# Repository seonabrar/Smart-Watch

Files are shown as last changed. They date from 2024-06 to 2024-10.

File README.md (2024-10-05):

# SMART WATCH – HEALTH AND FITNESS MONITORING SYSTEM

## ABSTRACT
This project presents the design and implementation of a multi-functional embedded system integrating various sensors and modules for environmental monitoring, user interaction, and health metrics. The core of the system is the Seeed Studio Xiao NRF52840 microcontroller, which orchestrates the operation of several connected components. 

## INTRODUCTION
The purpose of this document is to specify the requirements, implementation, and testing plan for Health and Fitness Monitoring System, also referred to as the "Smart Watch." This system is designed to cater to outdoor enthusiasts by providing real-time tracking and monitoring of vital health metrics and activity levels. The document aims to outline what the device is intended to achieve, how it has implemented, and the testing procedures to ensure that it meets the specified requirements. The ultimate goal is to enhance performance, safety, and overall well-being during outdoor activities such as hiking, trail running, and mountain biking.

## Block Diagram

This block diagram illustrates the connections between the Seeed Xiao Nrf52840 microcontroller and various sensors used in the Health and Fitness Monitoring System. The sensors connected via I2C are shown in blue arrows (input sensors), while the display connected via SPI is shown with a red arrow (output sensor).

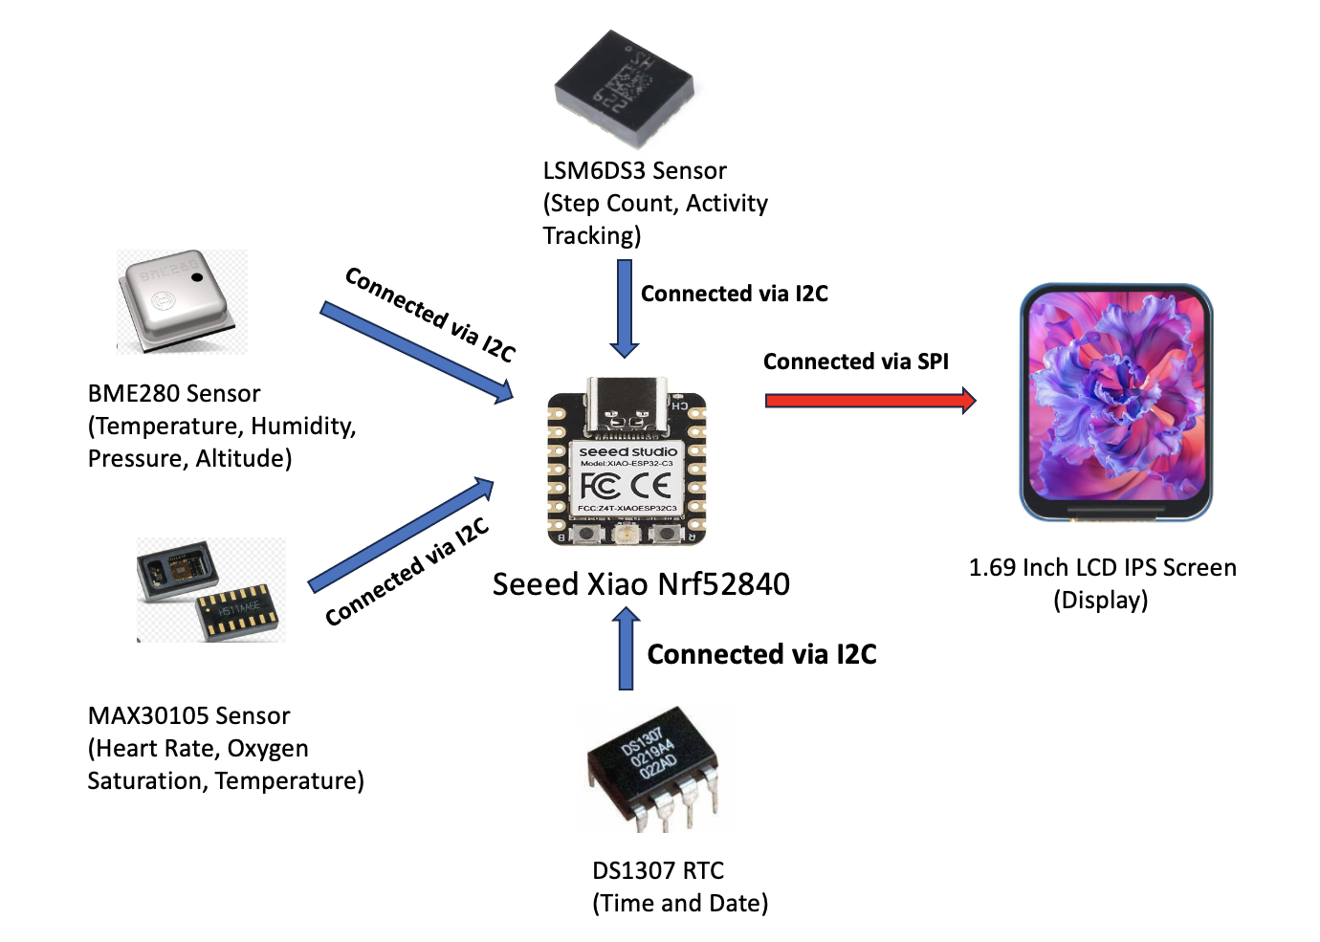
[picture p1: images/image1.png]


## Schematic

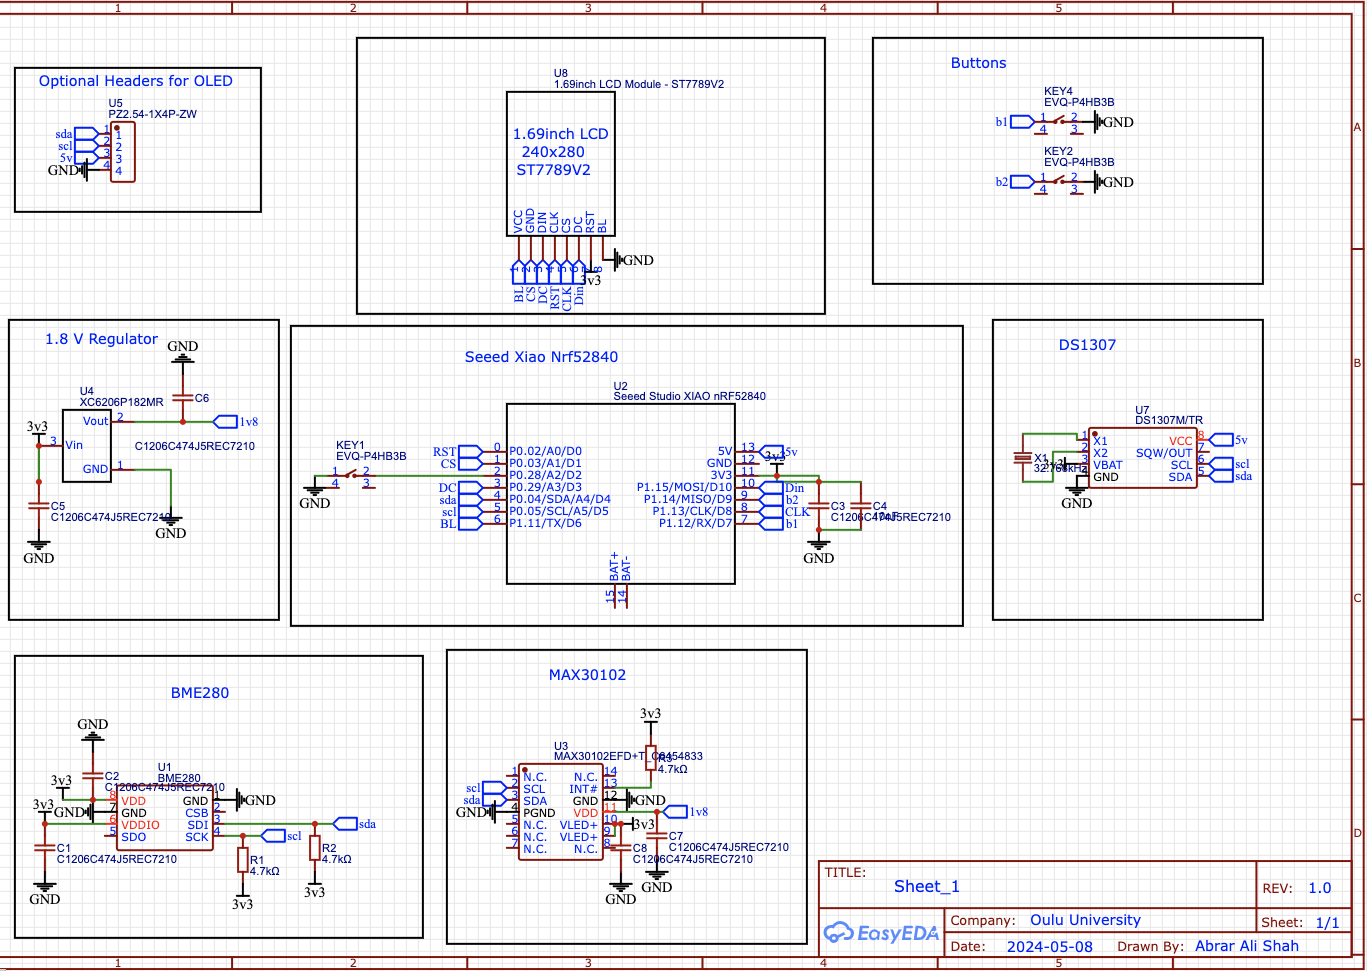
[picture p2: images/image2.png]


## PCB

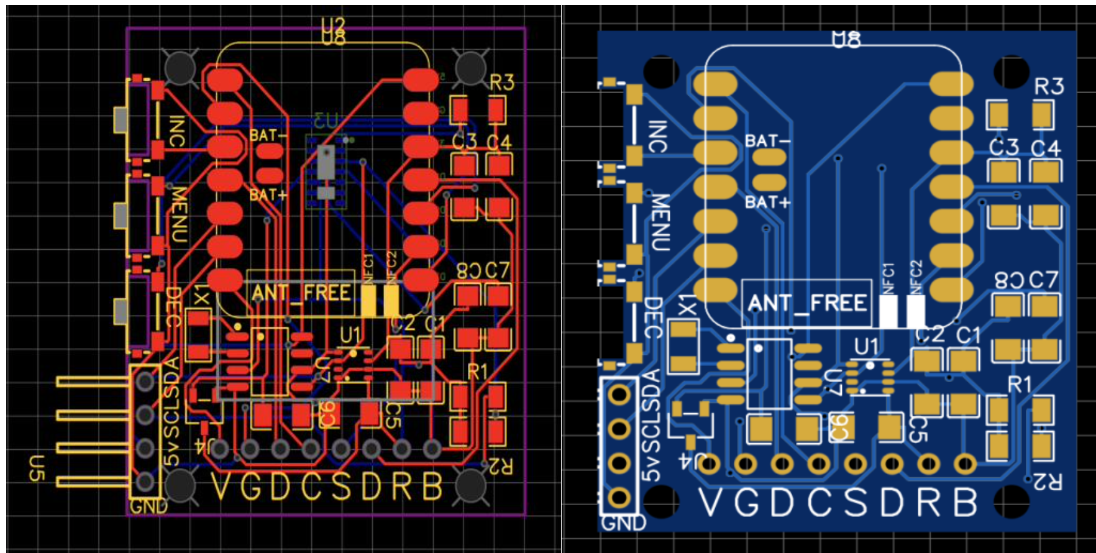
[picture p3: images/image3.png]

            Figure:  2D - PCB Layout for the Device.

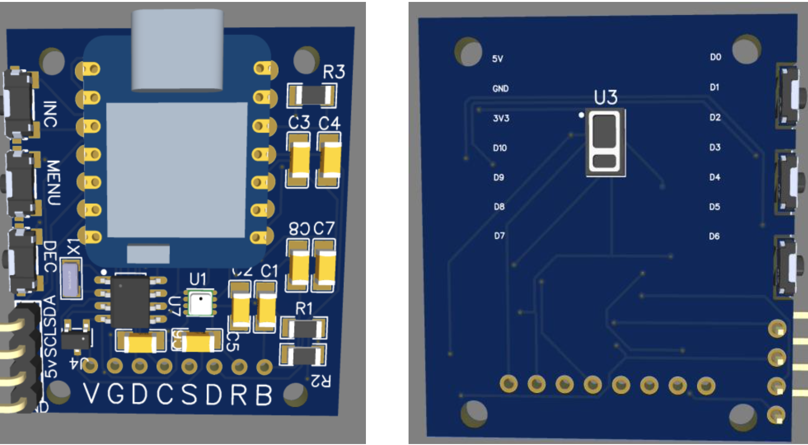
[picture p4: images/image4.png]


             Figure: 3D - PCB Layout for the Device.

## Software 
The software for the Seeed Xiao Based Health and Fitness Monitoring System was designed to manage sensor data acquisition, processing and display management. The software architecture was modular to facilitate ease of development, testing, and future enhancements.

## Software Architecture
The software is divided into several modules, each responsible for specific functionalities:
• Sensor Data Acquisition: Manages communication with sensors (MAX30105, BME280, LSM6DS3, DS1307) using I2C and SPI protocols to collect raw data.
• Data Processing and Analysis: Processes raw sensor data to derive meaningful health metrics and activity data.
• Display Management: Updates the 1.69 Inch LCD IPS screen with the latest health metrics and activity data.
• Power Management: Implements various power-saving strategies to extend battery life, including using deep sleep mode during periods of inactivity.

## Power Consumption and Battery Life Calculation

### Step 1: Current Consumption of Each Component

The current consumption of each component is as follows:

- **Seeed Xiao NRF52840**:
  - Active Mode (without BLE): ~6 mA
  - Idle Mode: ~1.5 mA
  - Deep Sleep: ~0.1 mA

- **LSM6DS3 (Accelerometer + Gyroscope)**:
  - Active Mode: ~0.67 mA
  - Power Down Mode: ~1 µA

- **MAX30105 (Heart Rate Monitor)**:
  - Typical: ~1.6 mA (continuous monitoring)
  - Standby: ~0.7 µA

- **DS1307 (RTC)**:
  - Typical: ~1.5 mA (when accessing data)
  - Standby: ~1.1 µA (when only keeping time)

- **BME280 (Temperature, Humidity, Pressure Sensor)**:
  - Active Mode: ~0.68 mA
  - Sleep Mode: ~0.1 µA

- **ST7789 Display**:
  - Active (with backlight on): ~7 mA
  - Standby: ~0.2 mA

### Step 2: Total Current Consumption

Assuming all components are active (no sleep mode), the total current consumption is calculated as:

- **Seeed Xiao NRF52840** (Active Mode): 6 mA
- **LSM6DS3** (Active Mode): 0.67 mA
- **MAX30105** (Typical): 1.6 mA
- **DS1307** (Typical): 1.5 mA
- **BME280** (Active Mode): 0.68 mA
- **ST7789 Display** (with backlight): 7 mA

**Total Current Consumption**:  
`6 mA + 0.67 mA + 1.6 mA + 1.5 mA + 0.68 mA + 7 mA = 17.45 mA`

### Step 3: Battery Life Calculation

Using a **3.7V 300mAh LiPo battery**:

- **Battery Capacity**: 300 mAh = 0.3 Ah
- **Battery Life** (in hours):  
  `Battery Life = Battery Capacity (Ah) / Total Current Consumption (A)`  
  `Battery Life = 0.3 Ah / 0.01745 A ≈ 17.2 hours`

## Procedure

- When Smart watch is Powered it shows Date and Time as below on Display.
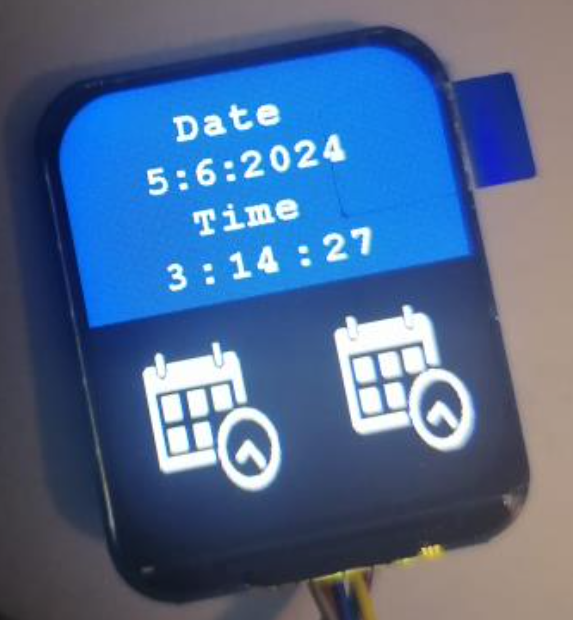
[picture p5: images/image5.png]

- When Button is pressed, screen changes and shows Heart Rate as below on Display.
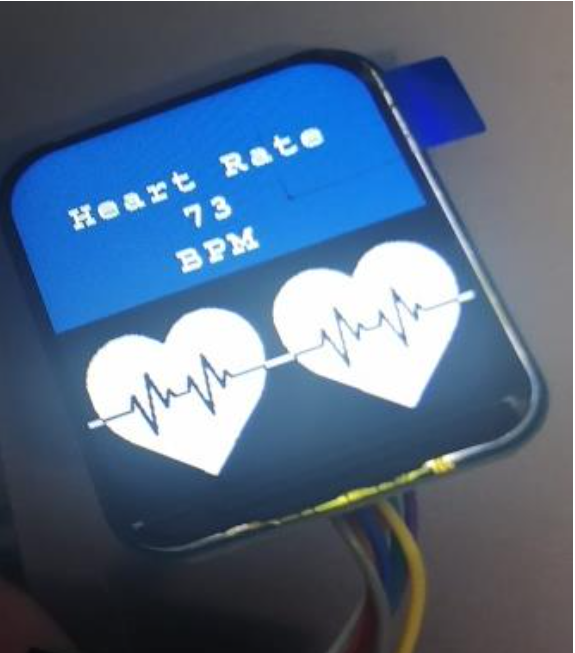
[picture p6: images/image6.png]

- When Button is pressed, screen changes and shows Tempertature and Humidity as below on Display.
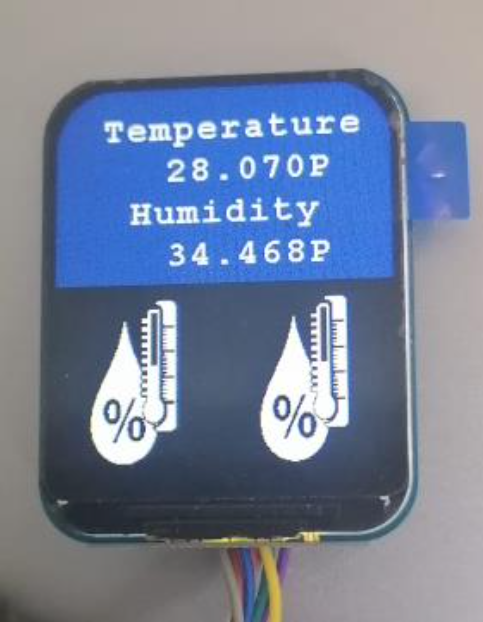
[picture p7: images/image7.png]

- When Button is pressed, screen changes and shows Altitude and Pressure as below on Display.
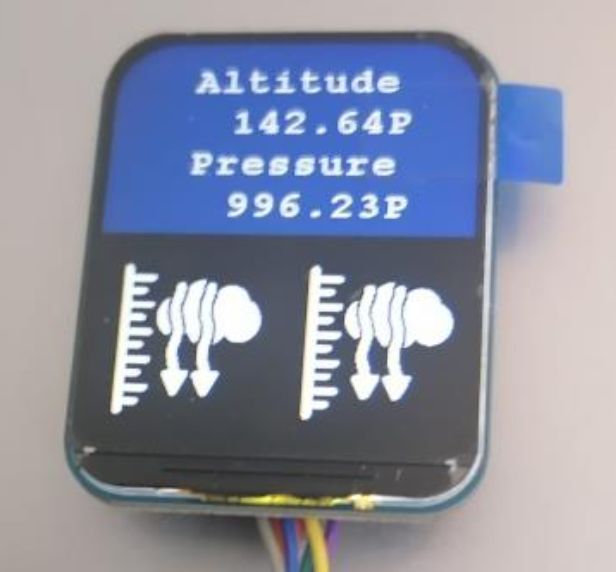
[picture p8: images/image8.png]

- When Button is pressed, screen changes and shows Steps Count as below on Display and so on.
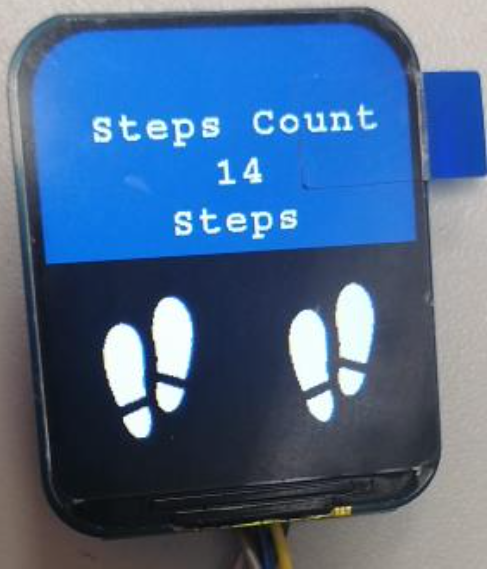
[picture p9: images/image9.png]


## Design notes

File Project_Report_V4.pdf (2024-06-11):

# SMART WATCH – HEALTH AND FITNESS MONITORING SYSTEM

Embedded System Project

ABSTRACT
This project presents the design and implementation of

a multi-functional embedded system integrating various

sensors and modules for environmental monitoring,

user interaction, and health metrics. The core of the

system is the Seeed Studio Xiao NRF52840

microcontroller, which orchestrates the operation of

several connected components.

GROUP 4

Abrar Ali Shah
Sabbir Hossain

Project Repository
https://github.com/seonabrar/Smart-Watch

Table of Contents

### 1 INTRODUCTION

1.1 Purpose

The purpose of this document is to specify the requirements, implementation, and testing

plan for Health and Fitness Monitoring System, also referred to as the "Smart Watch." This

system is designed to cater to outdoor enthusiasts by providing real-time tracking and

monitoring of vital health metrics and activity levels. The document aims to outline what

the device is intended to achieve, how it has implemented, and the testing procedures to

ensure that it meets the specified requirements. The ultimate goal is to enhance

performance, safety, and overall well-being during outdoor activities such as hiking, trail

running, and mountain biking.

1.2 Scope

The scope of this document includes three main sections: requirement specification,

implementation specification, and testing plan.

Requirement Specification: This section defines the functional, physical, and electrical

requirements of the smart watch. It includes detailed descriptions of what the device must

do, how it should operate, and any constraints or limitations that must be considered.

Implementation Specification: This section provides a detailed description of the

implementation techniques, hardware components, software architecture, and protocols

used in the development of the smart watch. It covers the design of the printed circuit board

(PCB), the selection of sensors and other components, and the software that will drive the

device.

Test Plan: This section outlines the tests that has been conducted during and after the

development process to ensure the device meets the specified requirements. The test plan

includes basic hardware tests, unit tests, integration tests, system tests, and regression tests.

1.3 Human Resources

The project team for Health and Fitness Monitoring System consists of Abrar Shah and

Sabbir Hossain from group 4. Both team members worked in all project phases. The

responsibilities are divided as follows:

Areas | Remarks | Group Member
Planning & Research | Initial Project Planning and Research | Abrar Shah, Sabbir Hossain
| Component Selection and Procurement | Abrar Shah, Sabbir Hossain
Electronics | Design and development of the electronic circuits and PCB layout by. | Abrar Shah, Sabbir Hossain
Software | Development of the firmware and software to operate the device. | Abrar Shah

Integration | Integration of hardware and software components to create a functional prototype. | Abrar Shah, Sabbir Hossain
Documentation | Creation and maintenance of project documentation, including this specification document. | Sabbir Hossain
Testing | Conducting tests to ensure the device meets all specified requirements. | Abrar Shah, Sabbir Hossain
Final Documentation | Creation and maintenance of project documentation, including this specification document. | Abrar Shah, Sabbir Hossain

1.4 Acronyms and Abbreviations

MCU: Microcontroller Unit

PCB: Printed Circuit Board

TFT: Thin Film Transistor

I2C: Two-wire serial communication protocol

ADC: Analog to Digital Converter

1.5 Overview

Health and Fitness Monitoring System is a smart watch designed for outdoor enthusiasts.

The primary objective of this device is to monitor and track vital health metrics and physical activity levels during outdoor pursuits. The device includes functionalities such

as heart rate monitoring, oxygen saturation measurement, step count tracking, altitude and

pressure, temperature, humidity and time keeping.

The smart watch is built around the Seeed Xiao Nrf52840 microcontroller, which provides

the necessary computational power. The device uses a variety of sensors to collect data,

which is then processed and displayed on a high-resolution graphical interface. The smart

watch is designed to be compact, lightweight, and durable, making it suitable for use in a

variety of outdoor environments.

### 2 Requirement Specification

2.1 Functional Requirements

Real-Time Health Monitoring:

The device provided accurate and real-time monitoring of vital health metrics, including

heart rate, oxygen saturation, and temperature. The MAX30105 sensor was used for this

purpose, leveraging its photoplethysmography (PPG) technology to measure changes in

blood volume. This enabled reliable heart rate tracking with an accuracy of ±1 bpm.

Activity Tracking and Analysis:

The device was capable of tracking and analyzing user activity levels, including step count

and calorie expenditure. The LSM6DS3 sensor, an accelerometer and gyroscope, was

utilized to detect motion and orientation changes with high precision. This allowed for

accurate step count tracking and detailed analysis of physical activity, enabling users to

monitor their fitness levels and performance during outdoor activities.

Environmental Awareness:

The device incorporated environmental sensors to provide real-time information about

ambient conditions such as temperature, humidity, pressure and altitude. The BME280

sensor was used, offering a wide measurement range and high accuracy (±1°C for

temperature, ±3% for humidity, and ±1 hPa for pressure). This allowed users to stay

informed about changing weather conditions, optimizing their performance based on

temperature and humidity levels, and ensuring safety during various outdoor activities.

Time and Date Tracking:

The device includes a DS1307 real-time clock (RTC) for accurate time and date keeping.

This is essential for logging activity data and synchronizing with external devices. The

RTC module ensures that timekeeping remains accurate even when the device is powered

off.

User Interface and Display:

The device featured a user-friendly interface with a 1.69 Inch LCD IPS screen, which had

a resolution of 240x280 pixels. This high-resolution display ensured clear and intuitive

visualization of health and activity data. The IPS technology provided wide viewing angles

and vibrant colors, enhancing the user experience by making the display easily readable in

various lighting conditions. The graphical interface allowed users to navigate through

different features, customize data visualization, and stay informed about their health and

activity levels.

2.2 Electrical Requirements

- Operating Voltage: The device operated at a standard voltage of 3.3V, suitable for

all components, including the microcontroller, sensors, and display. This ensured

efficient power consumption and compatibility across all hardware elements.

- Power Source and Management: The device features a rechargeable 3.7V

300mAh lithium-polymer (Li-Po) battery, providing sufficient capacity for at least

one day of regular use. To maximize battery life, various power management

techniques, including low-power modes and efficient task scheduling, have been

implemented. The Seeed Xiao NRF52840 microcontroller's deep sleep mode, which

reduces power consumption to an ultra-low 5 μA, is used during periods of

inactivity.

The device includes a micro-USB port for convenient recharging of the Li-Po

battery, ensuring compatibility with commonly available chargers and cables. The

integrated charging circuit manages the recharging process safely and efficiently,

preventing overcharging and ensuring battery longevity.

Power Specifications:

Battery: 3.7V 300mAh Li-Po

Operating Voltage: 3.3V @ 200mA

Charging Current: 50mA/100mA

Input Voltage: 5V DC

Standby Power Consumption: <5 μA

Overall, the device offers efficient power management and ultra-low power

consumption, making it suitable for extended use with minimal recharging

requirements.

2.3 Mechanical Requirements

The enclosure for end node device and main controller is 3d printed in fab lab.

### 3 Implementation Specification

3.1 Hardware

3.1.1 Components

1. MAX30105 Sensor:

The MAX30105 is an integrated particle-sensing module. It includes internal LEDs,

photodetectors, optical elements, and low-noise electronics with ambient light

rejection. The MAX30105 provides a complete system solution to ease the design-

in process of smoke detection applications including fire alarms. Due to its

extremely small size, the MAX30105 can also be used as a smoke detection sensor

for mobile and wearable devices. The MAX30105 operates on a single 1.8V power

supply and a separate 5.0V power supply for the internal LEDs. It communicates

through a standard I2C-compatible interface. The module can be shut down through

software with zero standby current, allowing the power rails to remain powered at

all times.

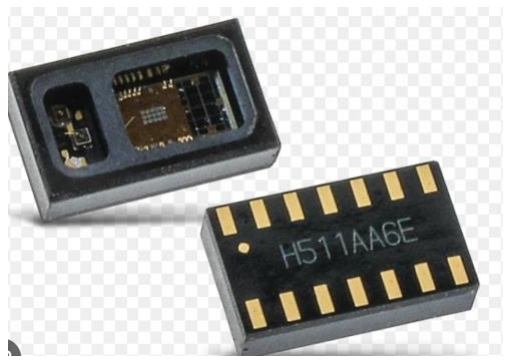
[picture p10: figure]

Figure: 3.1 MAX30105 sensing module.

2. BME280 Sensor:

The BME280 is as combined digital humidity, pressure and temperature sensor

based on proven sensing principles. The sensor module is housed in an extremely compact metal-lid LGA package with a footprint of only 2.5 × 2.5 mm² with a height

of 0.93 mm. Its small dimensions and its low power consumption allow the

implementation in battery driven devices such as handsets, GPS modules or

watches. The BME280 is register and performance compatible to the Bosch

Sensortec BMP280 digital pressure sensor. The BME280 achieves high

performance in all applications requiring humidity and pressure measurement.

These emerging applications of home automation control, in-door navigation,

fitness as well as GPS refinement require a high accuracy and a low TCO at the

same time. The humidity sensor provides an extremely fast response time for fast

context awareness applications and high overall accuracy over a wide temperature

range. The pressure sensor is an absolute barometric pressure sensor with extremely

high accuracy and resolution and drastically lower noise than the Bosch Sensortec

BMP180. The integrated temperature sensor has been optimized for lowest noise

and highest resolution. Its output is used for temperature compensation of the

pressure and humidity sensors and can also be used for estimation of the ambient

temperature. The sensor provides both SPI and I²C interfaces and can be supplied

using 1.71 to 3.6 V for the sensor supply VDD and 1.2 to 3.6 V for the interface

supply VDDIO. Measurements can be triggered by the host or performed in regular

intervals. When the sensor is disabled, current consumption drops to 0.1 µA.

BME280 can be operated in three power modes:

- Sleep mode
- Normal mode
- Forced mode

In order to tailor data rate, noise, response time and current consumption to the needs

of the user, a variety of oversampling modes, filter modes and data rates can be

selected.

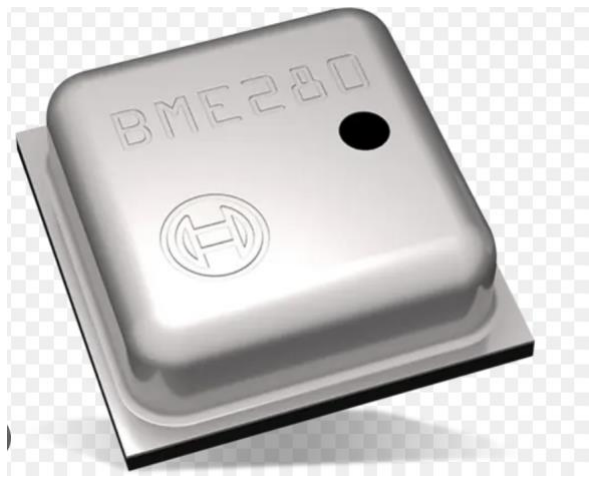
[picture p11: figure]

Figure: 3.2 BME280 Sensor

3. LSM6DS3 Sensor:

The LSM6DS3 is an advanced system-in-package that integrates a high-

performance 3-axis digital accelerometer and a 3-axis digital gyroscope. This sensor

module is designed to deliver exceptional motion sensing capabilities while

maintaining low power consumption, making it ideal for a variety of applications

including smartphones, tablets, and wearable devices.

The LSM6DS3 offers power-efficient modes, with consumption as low as 1.25 mA

in high-performance mode and even lower in power-down or low-power modes. It

supports an “always-on” experience with low power consumption for both the

accelerometer and gyroscope. This feature makes it suitable for applications

requiring continuous motion detection, such as pedometers, step counters, and tilt

functions.

In terms of sensing capabilities, the LSM6DS3 provides full-scale acceleration

ranges of ±2g, ±4g, ±8g, and ±16g, and angular rate ranges of ±125, ±250, ±500,

±1000, and ±2000 degrees per second (dps). The module also includes an integrated

temperature sensor, which enhances measurement accuracy by compensating for

temperature variations.

The LSM6DS3 is equipped with a smart FIFO buffer up to 8 kB, which can store

data for dynamic batching and supports advanced features such as pedometer, significant motion detection, and tilt functions. The sensor module’s high robustness

to mechanical shock and its compact footprint (2.5 mm x 3 mm x 0.83 mm) make it

a preferred choice for reliable product design.

Additionally, the LSM6DS3 offers configurable event detection and interrupt

generation, enabling applications such as tap and double-tap detection, free-fall

detection, and 6D orientation detection. Communication with the host processor is

facilitated through SPI or I2C serial interfaces, ensuring easy integration into a

variety of systems.

Overall, the LSM6DS3 is a versatile and efficient sensor module that provides

precise motion detection and measurement capabilities, making it suitable for a wide

range of consumer and industrial applications.

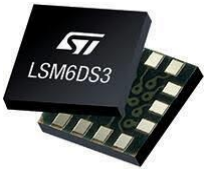
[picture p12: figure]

Figure: 3.3 LSM6DS3 Sensor

4. DS1307 RTC:

The DS1307 real-time clock was used to keep accurate time and date, which was

essential for logging activity data and synchronizing with external devices. The RTC

module ensured that timekeeping remained accurate even when the device was

powered off.

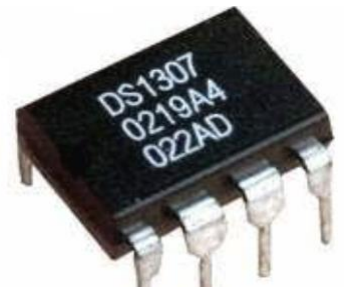
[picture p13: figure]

Figure 3.4 DS1307 RTC

5. 1.69 Inch LCD IPS Screen:

For the display we have used the 1.69” display with rounded corners. These IPS

display gives a very nice display contrast and colour saturation. This display uses

the ST7789 display driver. The ST7789 can support SPI bus frequency up to

100MHz. This will enable us to driver the display much faster providing better FPS.

The backlight is controlled using a N-Channel MOSFET. PWM is used to

control the brightness.

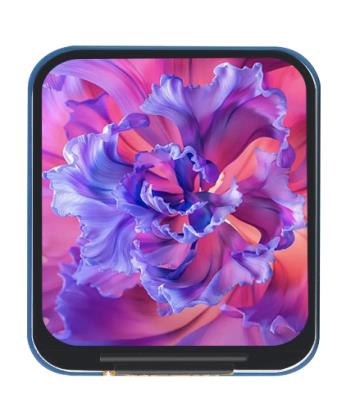
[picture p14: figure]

Figure: LCD display

### 3.1.2 Block Diagram

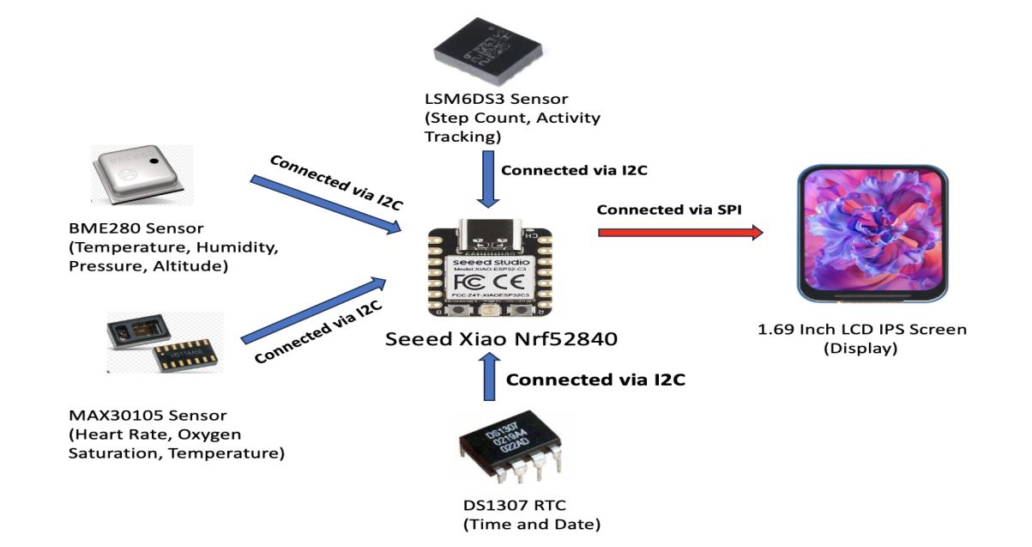
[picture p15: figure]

Figure: 3.5 Block Diagram of the overall device.

Table 3.1: Component Connections and Descriptions for the Device

Component | Description | Connection Type
Seeed Xiao Nrf52840 | Microcontroller | -
BME280 Sensor | Temperature, Humidity, Pressure, Altitude | I2C
MAX30105 Sensor | Heart Rate, Oxygen Saturation, Temperature | I2C
LSM6DS3 Sensor | Step Count, Activity Tracking | I2C
DS1307 RTC | Time and Date | I2C
1.69 Inch LCD IPS Screen | Display | SPI

This block diagram illustrates the connections between the Seeed Xiao Nrf52840

microcontroller and various sensors used in the Health and Fitness Monitoring System. The sensors connected via I2C are shown in blue arrows (input sensors), while the display

connected via SPI is shown with a red arrow (output sensor).

### 3.1.3 Microcontroller

Seeed Studio XIAO nRF52840 Sense is carrying Bluetooth 5.0 wireless capability and is

able to operate with low power consumption. Featuring onboard IMU and PDM, it can be

your best tool for embedded Machine Learning projects.

Features

- Versatile Microcontroller: Incorporate the Nordic nRF52840 chip with FPU,

operating up to 64 MHz, mounted multiple development ports, supported by

Arduino / CircuitPython

- Wireless Capabilities: Implement Bluetooth 5.0, BLE functions with onboard

antenna, also provide NFC connectivity

- Elaborate Power Design: Provide ultra-low power consumption as 5 μA in deep

sleep mode while supporting lithium battery charge management

- Advanced onboard Functionality: Assemble additional digital microphone and 6-

axis IMU in the tiny board for embedded Machine Learning applications

- Thumb-sized Design: 21 x 17.5mm, Seeed Studio XIAO series classic form-factor,

suitable for wearable devices

Seeed Studio XIAO nRF52840 Sense has an ultra-low power consumption of only 5 μA in

the deep sleep mode, the embedded BQ25101 chip supports battery charge management

which prolongs its use time. Moreover, Seeed Studio XIAO nRF52840 Sense supports the

USB Type-C interface which can supply power and download code. It also has rich On-

chip Memory of 1 MB flash and 256 kB RAM, and an Onboard Memory of 2 MB QSPI

flash. There are 11 digital i/o that can be used as PWM pins and 6 analog i/o that can be

used as ADC pins. It supports UART, IIC, and SPI all three common serial ports. 1 Reset

button, 1 3in-one LED, 1 Charge LED, and 1 Bluetooth antenna are on board, allowing

developers to debug their code very easily.

As the advanced yet smaller version of the Seeed Studio XIAO nRF52840, it carries two

extra onboard sensors. One of them is a digital microphone created through Pulse Density

Modulation(PDM) module on the nRF52840 chip. It can receive audio data in real-time

which allows it can be used for audio recognition. The board can receive audio data through

the MSM261D3526H1CPM microphone. The other one is 6-axis Inertial Measurement

Unit(IMU) which can be applied in TinyML projects like gesture recognition.

The powerful performance makes it perfect for TinyML AIoT projects requiring

gesture/voice recognition, and the tiny size allows it to be used in wearable devices and

Internet of Things projects, not just for prototypes but the mass production. Furthermore,

Seeed Studio XIAO nRF52840 Sense is friendly to the communities for its strong software

compatibilities, which supports Arduino, Micropython, and CircuitPython. Except for the

software, flexible I/O allows it to speak to almost any external device.

### 3.1.4 Schematic

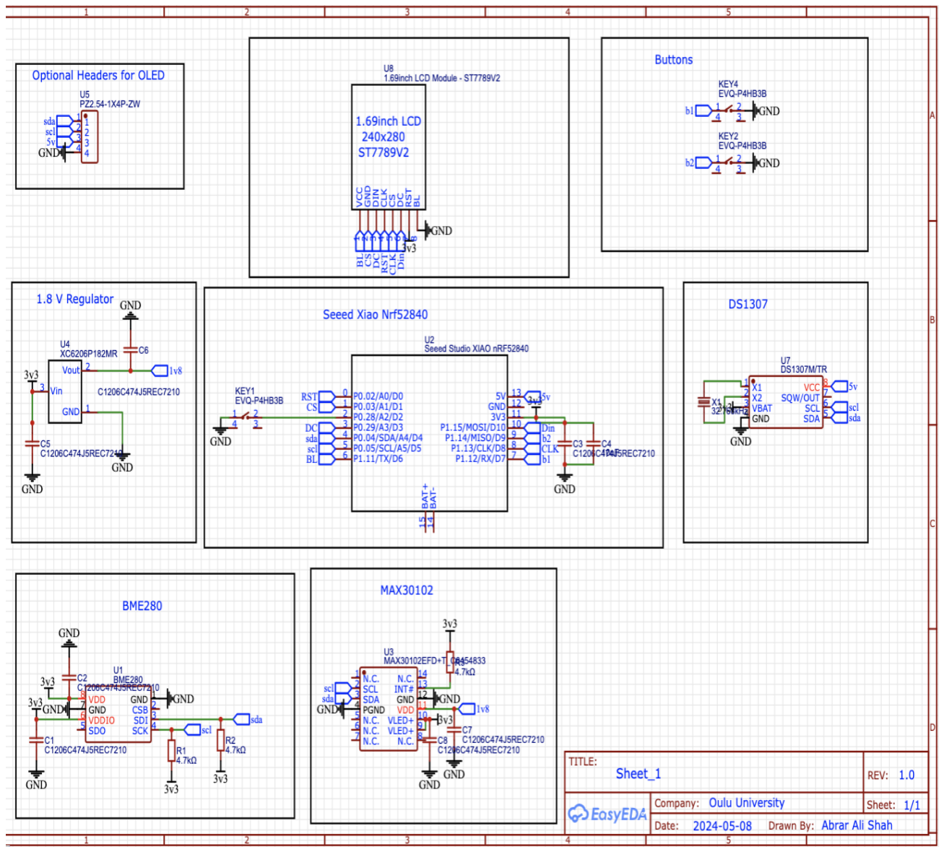
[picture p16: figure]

Figure 3.6: Schematic Diagram of the device

### 3.1.5 PCB

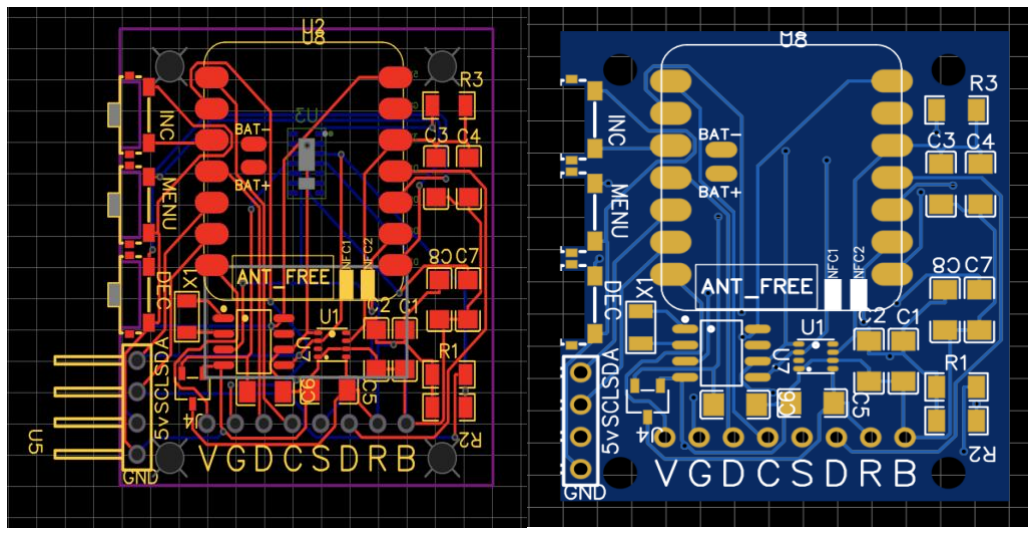
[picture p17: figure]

Figure: 3.7 2D - PCB Layout for the Device.

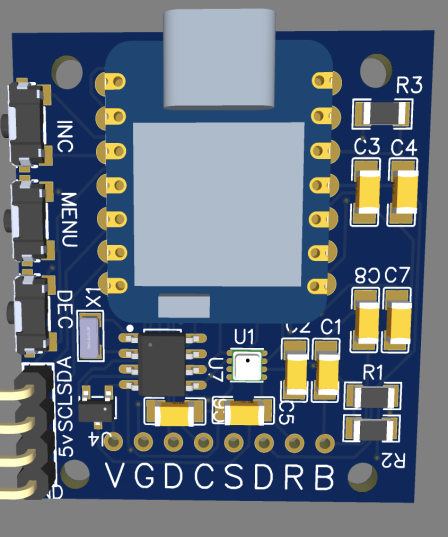
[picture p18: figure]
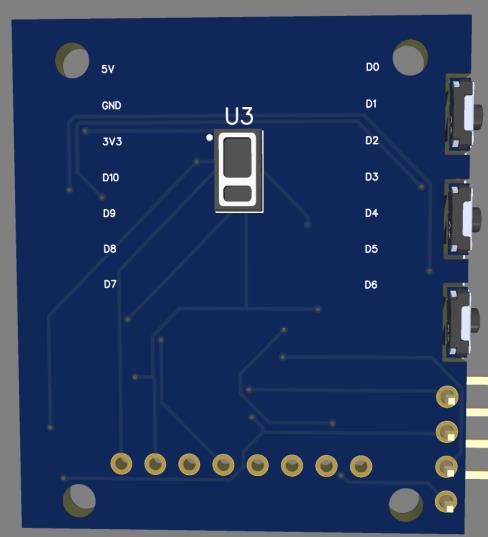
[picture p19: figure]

Figure: 3.8 3D - PCB Layout for the Device.

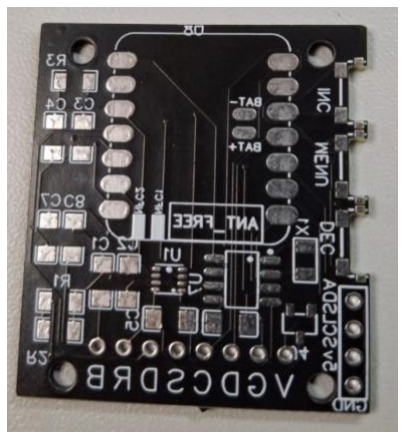
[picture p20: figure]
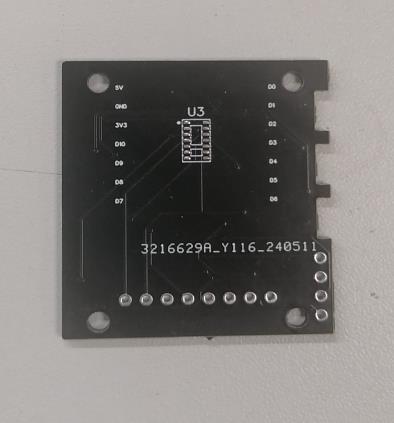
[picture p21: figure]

Figure: 3.9 Before assembly of components on the device.

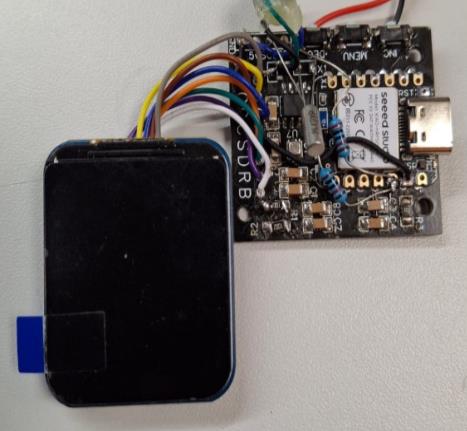
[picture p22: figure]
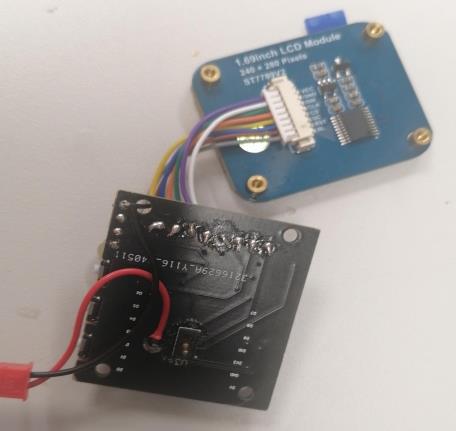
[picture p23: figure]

Figure: 3.10 After assembly of components on the device.

### 3.2 Software

The software for the Seeed Xiao Based Health and Fitness Monitoring System was

designed to manage sensor data acquisition, processing and display management. The

software architecture was modular to facilitate ease of development, testing, and future

enhancements.

### 3.2.1 Software Architecture

The software is divided into several modules, each responsible for specific functionalities:

- Sensor Data Acquisition: Manages communication with sensors (MAX30105,

BME280, LSM6DS3, DS1307) using I2C and SPI protocols to collect raw data.

- Data Processing and Analysis: Processes raw sensor data to derive meaningful

health metrics and activity data.

- Display Management: Updates the 1.69 Inch LCD IPS screen with the latest health

metrics and activity data.

- Power Management: Implements various power-saving strategies to extend battery

life, including using deep sleep mode during periods of inactivity.

- #include <st7789v2.h>
- #include "SPI.h"
- #include "Logo.h"

•
- #include "Wire.h"

•
- #include "MAX30105.h"
- #include "heartRate.h"

•
- #include <DS1307.h>

•
- #include <Adafruit_Sensor.h>
- #include <Adafruit_BME280.h>

•
- #include "LSM6DS3.h"

•
- DS1307 rtc;

•
- MAX30105 particleSensor;

•
- | #define CLEAR_STEP | true
- #define NOT_CLEAR_STEP false

•
- //Create a instance of class LSM6DS3
- LSM6DS3 pedometer(I2C_MODE, 0x6A); //I2C device address 0x6A

•
- const byte RATE_SIZE = 5; // Increase this for more averaging. 4 is good.
- byte rates[RATE_SIZE]; // Array of heart rates
- byte rateSpot = 0;
- long lastBeat = 0; // Time at which the last beat occurred

•
- float beatsPerMinute;
- int beatAvg;

•
- st7789v2 Display;

•
- #define BUTTON_PIN D7

•
- unsigned long lastDisplayUpdate = 0;

•
- // Variable to track the button press count
- volatile int Screen = 0;
- volatile int publishImage = 0;

•
- uint8_t sec, mins, hour, day, month;
- uint16_t year;

•
- Adafruit_BME280 bme; // I2C

•
- unsigned long delayTime;
- #define SEALEVELPRESSURE_HPA (1013.25)

•

- // Interrupt Service Routine (ISR) for button press
- void handleButtonPress() {
- publishImage = 0;
- Screen++;
- }

•
- //Setup pedometer mode
- int config_pedometer(bool clearStep) {
- uint8_t errorAccumulator = 0;
- uint8_t dataToWrite = 0; //Temporary variable

•
- //Setup the accelerometer******************************
- dataToWrite = 0;

•
- // dataToWrite |= LSM6DS3_ACC_GYRO_BW_XL_200Hz;
- dataToWrite |= LSM6DS3_ACC_GYRO_FS_XL_2g;
- dataToWrite |= LSM6DS3_ACC_GYRO_ODR_XL_26Hz;

•
- // Step 1: Configure ODR-26Hz and FS-2g
- errorAccumulator += pedometer.writeRegister(LSM6DS3_ACC_GYRO_CTRL1_XL, dataToWrite);

•
- // Step 2: Set bit Zen_G, Yen_G, Xen_G, FUNC_EN, PEDO_RST_STEP(1 or 0)
- if (clearStep) {
- errorAccumulator += pedometer.writeRegister(LSM6DS3_ACC_GYRO_CTRL10_C, 0x3E);
- } else {
- errorAccumulator += pedometer.writeRegister(LSM6DS3_ACC_GYRO_CTRL10_C, 0x3C);
- }

•
- // Step 3: Enable pedometer algorithm
- errorAccumulator += pedometer.writeRegister(LSM6DS3_ACC_GYRO_TAP_CFG1, 0x40);

•
- //Step 4: Step Detector interrupt driven to INT1 pin, set bit INT1_FIFO_OVR
- errorAccumulator += pedometer.writeRegister(LSM6DS3_ACC_GYRO_INT1_CTRL, 0x10);

•
- return errorAccumulator;
- }

•

- void setup() {
- Serial.begin(115200);
- // Configure the button pin as input with an internal pull-up resistor
- pinMode(BUTTON_PIN, INPUT_PULLUP);
- // Attach the interrupt to the button pin
- // Trigger the ISR on the falling edge (button press)
- attachInterrupt(digitalPinToInterrupt(BUTTON_PIN), handleButtonPress, FALLING);

•
- Serial.println("Button interrupt setup complete.");

•
- // Initialize sensor
- if (!particleSensor.begin(Wire, I2C_SPEED_FAST)) { // Use default I2C port, 400kHz speed
- Serial.println("MAX30105 was not found. Please check wiring/power.");
- while (1);
- }
- Serial.println("Place your index finger on the sensor with steady pressure.");

•
- particleSensor.setup(); // Configure sensor with default settings
- particleSensor.setPulseAmplitudeRed(0x0A); // Turn Red LED to low to indicate sensor is running
- particleSensor.setPulseAmplitudeGreen(0); // Turn off Green LED

•
- Serial.println("Init RTC...");
- rtc.begin();

•
- //only set the date+time one time
- rtc.set(0, 11, 3, 5, 6, 2024); //08:00:00 24.12.2014 //sec, min, hour, day, month, year

•
- //stop/pause RTC
- // rtc.stop();

•
- //start RTC
- rtc.start();

•
- // default settings
- unsigned status = bme.begin();
- // You can also pass in a Wire library object like &Wire2
- // status = bme.begin(0x76, &Wire2)

- if (!status) {
- Serial.println("Could not find a valid BME280 sensor, check wiring, address, sensor ID!");
- Serial.print("SensorID was: 0x"); Serial.println(bme.sensorID(),16);
- | Serial.print(" | ID of 0xFF probably means a bad address, a BMP 180 or BMP 085\n");
- Serial.print(" ID of 0x56-0x58 represents a BMP 280,\n");
- | Serial.print(" | ID of 0x60 represents a BME 280.\n");
- | Serial.print(" | ID of 0x61 represents a BME 680.\n");
- while (1) delay(10);
- }

•
- Serial.println("-- Default Test --");
- delayTime = 1000;

•
- if (pedometer.begin() != 0) {
- Serial.println("Device error");
- } else {
- Serial.println("Device OK!");
- }

•
- //Configure LSM6DS3 as pedometer
- if (0 != config_pedometer(NOT_CLEAR_STEP)) {
- Serial.println("Configure pedometer fail!");
- }
- Serial.println("Success to Configure pedometer!");

•
- Display.SetRotate(0);
- Display.Init();
- Display.SetBacklight(100);
- Display.Clear(DARKBLUE);
- }

•
- void loop() {
- if (Screen == 0){
- DateAndTime();
- }

•
- if (Screen == 1){

- HRApp();
- }

•
- if (Screen == 2){
- TempAndHum();
- }

•
- if (Screen == 3){
- AltAndPress();
- }

•
- if (Screen == 4){
- StepCounter();
- }

•
- if (Screen >= 5){

•
- Screen = 0;
- }

•

- }

•
- void HRApp() {
- long irValue = particleSensor.getIR(); // Reading the IR value to know if there's a finger on the sensor

•
- if (checkForBeat(irValue) == true) { // If a heartbeat is detected
- long delta = millis() - lastBeat; // Measure duration between two beats
- lastBeat = millis();
- beatsPerMinute = 60 / (delta / 1000.0); // Calculating the BPM

•
- if (beatsPerMinute < 255 && beatsPerMinute > 20) {
- rates[rateSpot++] = (byte)beatsPerMinute; // Store this reading in the array
- | rateSpot %= RATE_SIZE; | // Wrap variable

•
- // Take average of readings
- beatAvg = 0;
- for (byte x = 0; x < RATE_SIZE; x++) {

- beatAvg += rates[x];
- }
- beatAvg /= RATE_SIZE;
- }
- }

•
- if (millis() - lastDisplayUpdate > 500) {
- if (publishImage == 0){
- Display.Clear(DARKBLUE);
- Display.DrawString_EN(0, 50, " Heart Rate ", &Font24, DARKBLUE, WHITE);
- Display.DrawString_EN(70, 110, " BPM ", &Font24, DARKBLUE, WHITE);
- Display.DrawImage(gImage_heart, 0, 140, 240, 280);
- // Display.DrawNum(100, 220, 123456, &Font24, RED, BRED);
- publishImage = 1;
- }
- if (publishImage == 1){
- Display.DrawNum(100, 80, beatAvg, &Font24, DARKBLUE, WHITE);
- }
- lastDisplayUpdate = millis();
- }

•
- Serial.print("IR=");
- Serial.print(irValue);
- Serial.print(", BPM=");
- Serial.print(beatsPerMinute);
- Serial.print(", Avg BPM=");
- Serial.print(beatAvg);
- if (irValue < 60000) {
- Serial.print(" No finger?");
- }
- if (millis() - lastBeat > 5000) {
- beatsPerMinute = 0;
- beatAvg = 0;
- }
- Serial.println();
- }

•

- void DateAndTime(){
- if (publishImage == 0){
- Display.Clear(DARKBLUE);

•
- Display.DrawString_EN(40, 20, " Date ", &Font24, DARKBLUE, WHITE);
- Display.DrawString_EN(40, 80, " Time ", &Font24, DARKBLUE, WHITE);
- //Display.DrawImage(gImage_heart, 0, 140, 240, 280);
- //Display.DrawImage(gImage_heart, 0, 140, 240, 280);
- Display.DrawImage(gImage_time, 0, 140, 240, 280);
- // Display.DrawNum(100, 220, 123456, &Font24, RED, BRED);

•
- publishImage = 1;
- }
- if (publishImage == 1){
- rtc.get(&sec, &mins, &hour, &day, &month, &year);
- Display.DrawNum(50, 50, day, &Font24, DARKBLUE, WHITE);
- Display.DrawString_EN(65, 50, ":", &Font24, DARKBLUE, WHITE);
- Display.DrawNum(80, 50, month, &Font24, DARKBLUE, WHITE);
- Display.DrawString_EN(95, 50, ":", &Font24, DARKBLUE, WHITE);
- Display.DrawNum(110, 50, year, &Font24, DARKBLUE, WHITE);

•
- Display.DrawNum(50, 110, hour, &Font24, DARKBLUE, WHITE);
- Display.DrawString_EN(70, 110, ":", &Font24, DARKBLUE, WHITE);
- Display.DrawNum(90, 110, mins, &Font24, DARKBLUE, WHITE);
- Display.DrawString_EN(130, 110, ":", &Font24, DARKBLUE, WHITE);
- Display.DrawNum(150, 110, sec, &Font24, DARKBLUE, WHITE);

•

- }
- }

•
- void TempAndHum(){
- if (publishImage == 0){
- Display.Clear(DARKBLUE);

•
- Display.DrawString_EN(0, 20, " Temperature ", &Font24, DARKBLUE, WHITE);
- Display.DrawString_EN(20, 80, " Humidity ", &Font24, DARKBLUE, WHITE);
- //Display.DrawImage(gImage_heart, 0, 140, 240, 280);

- Display.DrawImage(gImage_temp, 0, 140, 240, 280);

•
- publishImage = 1;
- }
- if (publishImage == 1){
- Display.DrawFloatNum(80, 50, bme.readTemperature(), 3, &Font24, WHITE, DARKBLUE);
- Display.DrawFloatNum(80, 110, bme.readHumidity(), 3, &Font24, WHITE, DARKBLUE);
- }
- }

•
- void AltAndPress(){
- if (publishImage == 0){
- Display.Clear(DARKBLUE);

•
- Display.DrawString_EN(20, 20, " Altitude ", &Font24, DARKBLUE, WHITE);
- Display.DrawString_EN(20, 80, " Pressure ", &Font24, DARKBLUE, WHITE);
- //Display.DrawImage(gImage_heart, 0, 140, 240, 280);
- Display.DrawImage(gImage_alt, 0, 140, 240, 280);

•
- publishImage = 1;
- }
- if (publishImage == 1){
- Display.DrawFloatNum(80, 50, bme.readAltitude(SEALEVELPRESSURE_HPA), 2, &Font24, WHITE, DARKBLUE);
- Display.DrawFloatNum(80, 110, bme.readPressure()/ 100.0F, 2, &Font24, WHITE, DARKBLUE);
- }

•

- }

•
- void StepCounter(){
- uint8_t dataByte = 0;
- uint16_t stepCount = 0;

•
- pedometer.readRegister(&dataByte, LSM6DS3_ACC_GYRO_STEP_COUNTER_H);
- stepCount = (dataByte << 8) & 0xFFFF;

•
- pedometer.readRegister(&dataByte, LSM6DS3_ACC_GYRO_STEP_COUNTER_L);

- stepCount |= dataByte;

•
- Serial.print("Step: ");
- Serial.println(stepCount);

•

•

•
- if (publishImage == 0){
- Display.Clear(DARKBLUE);

•
- Display.DrawString_EN(0, 50, " Steps Count ", &Font24, DARKBLUE, WHITE);
- Display.DrawString_EN(80, 110, "Steps", &Font24, DARKBLUE, WHITE);
- //Display.DrawImage(gImage_heart, 0, 140, 240, 280);
- Display.DrawImage(gImage_stepscount, 0, 140, 240, 280);
- // Display.DrawNum(100, 220, 123456, &Font24, RED, BRED);

•
- publishImage = 1;
- }
- if (publishImage == 1){
- Display.DrawNum(110, 80, stepCount, &Font24, DARKBLUE, WHITE);
- }

•
- delay(500);
- }

•

### 3.3 Cost Calculations

The cost calculations for the Seeed Xiao-Based Health and Fitness Monitoring System

were carefully planned to ensure affordability while maintaining high-quality components.

The total cost was divided into component costs and development tool costs.

3.3.1 Components

1. MAX30105 Sensor: $15
2. BME280 Sensor: $10

3. DS1307 RTC: $5
4. 1.69 Inch LCD IPS Screen: $20
5. Seeed Xiao Microcontroller: $7
6. Rechargeable Li-Po Battery: $20
7. PCB and Miscellaneous Components: $15

Total Component Cost: $90

3.3.2 Development Tools

1. Arduino IDE: Free
- The Arduino Integrated Development Environment (IDE) was used for

software development. Its open-source nature and wide community support

made it a cost-effective choice.

2. EasyEda: Free (Open Source)
- EasyEda were used for PCB design. Both tools are available for free, making

them ideal for budget-conscious projects.

Total Development Tool Cost: $400

3.3.3 Total Costs

The total cost of the project included both the component costs and the development tool

costs.

1. Component Costs: $90
2. Development Tool Costs: $400

Total Project Cost: $490

### 3.4 Tools

- Arduino IDE for software development.

### 4 Testing

### 4.1 Unit Tests

Unit tests were conducted to verify the functionality of individual components and modules

in the Seeed Xiao-Based Health and Fitness Monitoring System. Each unit test was

designed to ensure that the specific part of the system performed as expected under

predefined conditions.

### 4.1.1 Push Button Tests

Objective: To ensure the push button accurately registers presses and triggers the

appropriate actions. –

Test Setup: Connect a push button to the Seeed Xiao, configure it as an interrupt.

Procedure: Upload the code to the firmware and press the button under controlled

conditions. Verify the button press count and the associated actions.

Results:

// Define the button pin
#define BUTTON_PIN D7

// Variable to track the button press count volatile int buttonPressCount = 0;

// Interrupt Service Routine (ISR) for button press void handleButtonPress() {
buttonPressCount++;

}
void setup() {
Serial.begin(115200);
// put your setup code here, to run once: pinMode(BUTTON_PIN, INPUT_PULLUP);

attachInterrupt(digitalPinToInterrupt(BUTTON_PIN), handleButtonPress, FALLING);

}

void loop() {
// put your main code here, to run repeatedly: Serial.print("Button Press Count: "); Serial.println(buttonPressCount); delay(1000);
}

Results:

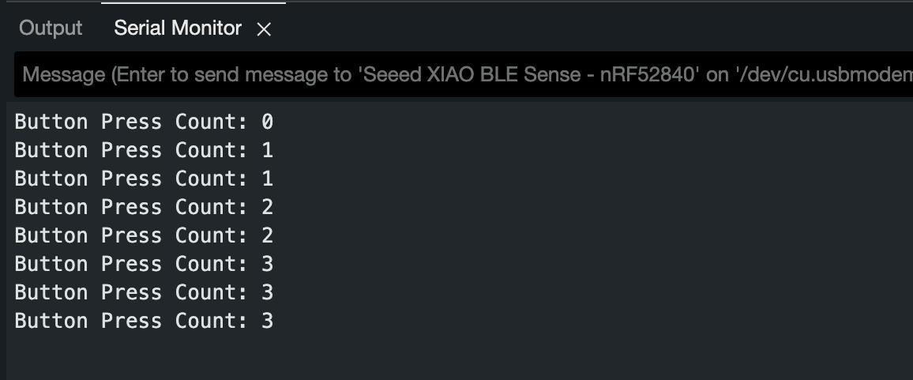
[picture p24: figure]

The test was successful in ensuring that each button press was accurately registered and

counted. The serial output provided a real-time count of button presses.

### 4.1.2 Sensor Tests

Objective: To ensure that each sensor accurately reads and transmits data.

1. MAX30105 Sensor:

- Test Setup: Connect the MAX30105 sensor to the Seeed Xiao and simulate

different heart rates and oxygen saturation levels.

- Procedure: Upload the below code to Firmware. Place the finger on Max30102

measure the sensor’s output under controlled conditions.

•
- #include <Wire.h>
- #include "MAX30105.h"

•
- #include "heartRate.h"

•
- MAX30105 particleSensor;

•
- const byte RATE_SIZE = 4; //Increase this for more averaging. 4 is good.
- byte rates[RATE_SIZE]; //Array of heart rates
- byte rateSpot = 0;
- long lastBeat = 0; //Time at which the last beat occurred

•
- float beatsPerMinute;
- int beatAvg;

•
- void setup()
- {
- Serial.begin(115200);
- Serial.println("Initializing...");

•
- // Initialize sensor
- if (!particleSensor.begin(Wire, I2C_SPEED_FAST)) //Use default I2C port, 400kHz speed
- {
- Serial.println("MAX30105 was not found. Please check wiring/power. ");
- while (1);
- }
- Serial.println("Place your index finger on the sensor with steady pressure.");

•
- particleSensor.setup(); //Configure sensor with default settings
- particleSensor.setPulseAmplitudeRed(0x0A); //Turn Red LED to low to indicate sensor is running

- particleSensor.setPulseAmplitudeGreen(0); //Turn off Green LED
- }

•
- void loop()
- {
- long irValue = particleSensor.getIR();

•
- if (checkForBeat(irValue) == true)
- {
- //We sensed a beat!
- long delta = millis() - lastBeat;
- lastBeat = millis();

•
- beatsPerMinute = 60 / (delta / 1000.0);

•
- if (beatsPerMinute < 255 && beatsPerMinute > 20)
- {
- rates[rateSpot++] = (byte)beatsPerMinute; //Store this reading in the array
- rateSpot %= RATE_SIZE; //Wrap variable

•
- //Take average of readings
- beatAvg = 0;
- for (byte x = 0 ; x < RATE_SIZE ; x++)
- beatAvg += rates[x];
- beatAvg /= RATE_SIZE;
- }
- }

•
- Serial.print("IR=");
- Serial.print(irValue);
- Serial.print(", BPM=");
- Serial.print(beatsPerMinute);
- Serial.print(", Avg BPM=");
- Serial.print(beatAvg);

•
- if (irValue < 50000)
- {

- Serial.print(" No finger?");
- beatAvg = 0;
- }

•
- Serial.println();
- }
- Result:

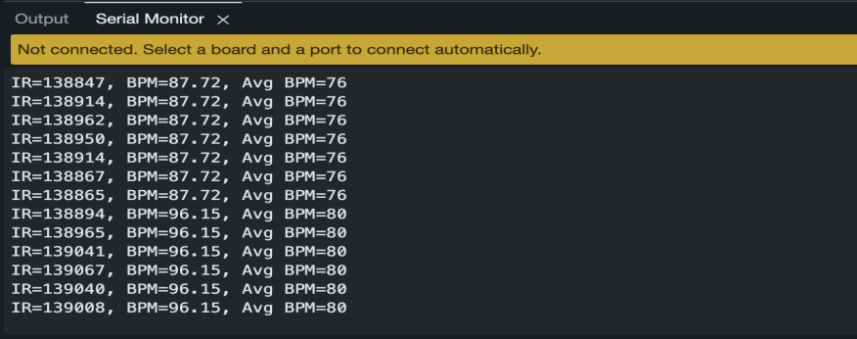
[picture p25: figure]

The sensor accurately detected heart rate, providing real-time data through the serial

output.

2. BME280 Sensor:
- Test Setup: Connect the BME280 sensor to the Seeed Xiao Nrf52840 and expose

it to different temperatures, humidity levels, and pressures.

- Procedure: Upload the below code to Firmware and measure the sensor’s output

under controlled conditions.

•
- #include <Wire.h>
- #include <Adafruit_Sensor.h>
- #include <Adafruit_BME280.h>

•

- #define SEALEVELPRESSURE_HPA (1013.25)

•
- Adafruit_BME280 bme; // I2C
- //Adafruit_BME280 bme(BME_CS); // hardware SPI
- //Adafruit_BME280 bme(BME_CS, BME_MOSI, BME_MISO, BME_SCK); // software SPI

•
- unsigned long delayTime;

•
- void setup() {
- Serial.begin(9600);
- while(!Serial); // time to get serial running
- Serial.println(F("BME280 test"));

•
- unsigned status;

•
- // default settings
- status = bme.begin();
- // You can also pass in a Wire library object like &Wire2
- // status = bme.begin(0x76, &Wire2)
- if (!status) {
- Serial.println("Could not find a valid BME280 sensor, check wiring, address, sensor ID!");
- Serial.print("SensorID was: 0x"); Serial.println(bme.sensorID(),16);
- | Serial.print(" | ID of 0xFF probably means a bad address, a BMP 180 or BMP 085\n");
- Serial.print(" ID of 0x56-0x58 represents a BMP 280,\n");
- | Serial.print(" | ID of 0x60 represents a BME 280.\n");
- | Serial.print(" | ID of 0x61 represents a BME 680.\n");
- while (1) delay(10);
- }

•
- Serial.println("-- Default Test --");
- delayTime = 1000;

•
- Serial.println();
- }

•
- void loop() {
- printValues();

- delay(delayTime);
- }

•
- void printValues() {
- Serial.print("Temperature = ");
- Serial.print(bme.readTemperature());
- Serial.println(" °C");

•
- Serial.print("Pressure = ");

•
- Serial.print(bme.readPressure() / 100.0F);
- Serial.println(" hPa");

•
- Serial.print("Approx. Altitude = ");
- Serial.print(bme.readAltitude(SEALEVELPRESSURE_HPA));
- Serial.println(" m");

•
- Serial.print("Humidity = ");
- Serial.print(bme.readHumidity());
- Serial.println(" %");

•
- Serial.println();
- }

•

- Result:

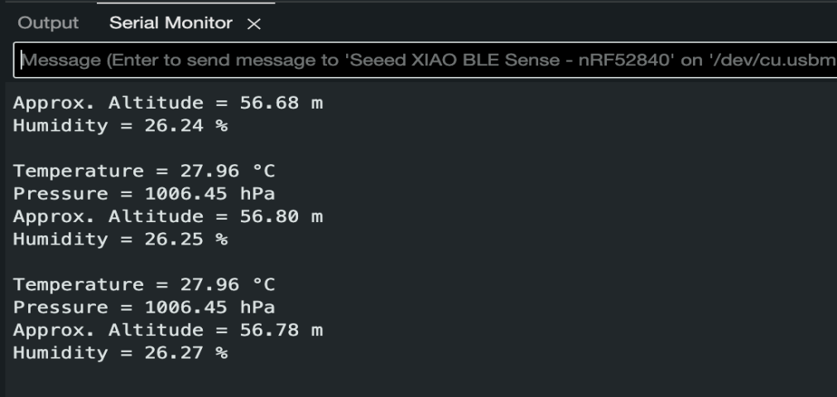
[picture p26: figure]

The BME280 sensor provided accurate readings for temperature, humidity, and

pressure, which were displayed on the serial monitor.

3. LSM6DS3 Sensor:
- Test Setup: Seeed Xiao has inbuilt LSM6DS3.
- Procedure: Upload the below code to Firmware and measure the sensor’s output

under controlled conditions.

- #include "LSM6DS3.h"
- #include "Wire.h"

•
- | #define CLEAR_STEP | true
- #define NOT_CLEAR_STEP false

•
- //Create a instance of class LSM6DS3
- LSM6DS3 pedometer(I2C_MODE, 0x6A); //I2C device address 0x6A

•
- void setup() {
- Serial.begin(9600);
- while (!Serial);
- if (pedometer.begin() != 0) {
- Serial.println("Device error");
- } else {
- Serial.println("Device OK!");

- }

•
- //Configure LSM6DS3 as pedometer
- if (0 != config_pedometer(NOT_CLEAR_STEP)) {
- Serial.println("Configure pedometer fail!");
- }
- Serial.println("Success to Configure pedometer!");
- }

•
- void loop() {
- uint8_t dataByte = 0;
- uint16_t stepCount = 0;

•
- pedometer.readRegister(&dataByte, LSM6DS3_ACC_GYRO_STEP_COUNTER_H);
- stepCount = (dataByte << 8) & 0xFFFF;

•
- pedometer.readRegister(&dataByte, LSM6DS3_ACC_GYRO_STEP_COUNTER_L);
- stepCount |= dataByte;

•
- Serial.print("Step: ");
- Serial.println(stepCount);

•
- delay(500);
- }

•
- //Setup pedometer mode
- int config_pedometer(bool clearStep) {
- uint8_t errorAccumulator = 0;
- uint8_t dataToWrite = 0; //Temporary variable

•
- //Setup the accelerometer******************************
- dataToWrite = 0;

•
- // dataToWrite |= LSM6DS3_ACC_GYRO_BW_XL_200Hz;
- dataToWrite |= LSM6DS3_ACC_GYRO_FS_XL_2g;
- dataToWrite |= LSM6DS3_ACC_GYRO_ODR_XL_26Hz;

•

- // Step 1: Configure ODR-26Hz and FS-2g
- errorAccumulator += pedometer.writeRegister(LSM6DS3_ACC_GYRO_CTRL1_XL, dataToWrite);

•
- // Step 2: Set bit Zen_G, Yen_G, Xen_G, FUNC_EN, PEDO_RST_STEP(1 or 0)
- if (clearStep) {
- errorAccumulator += pedometer.writeRegister(LSM6DS3_ACC_GYRO_CTRL10_C, 0x3E);
- } else {
- errorAccumulator += pedometer.writeRegister(LSM6DS3_ACC_GYRO_CTRL10_C, 0x3C);
- }

•
- // Step 3: Enable pedometer algorithm
- errorAccumulator += pedometer.writeRegister(LSM6DS3_ACC_GYRO_TAP_CFG1, 0x40);

•
- //Step 4: Step Detector interrupt driven to INT1 pin, set bit INT1_FIFO_OVR
- errorAccumulator += pedometer.writeRegister(LSM6DS3_ACC_GYRO_INT1_CTRL, 0x10);

•
- return errorAccumulator;
- }

•

- Result:

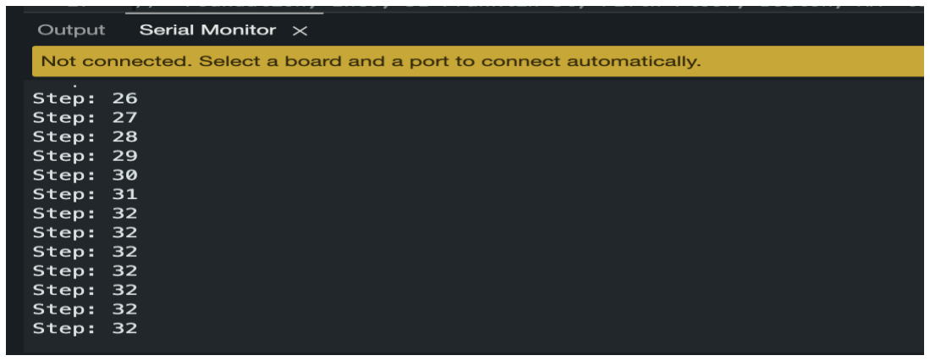
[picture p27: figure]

The LSM6DS3 sensor accurately tracked steps and provided reliable motion data,

which was printed on the serial monitor.

4. DS1307 RTC:
- Test Setup: Integrate the DS1307 RTC with the Seeed Xiao Nrf52840.
- Procedure: Procedure: Upload the below code to Firmware and measure the

sensor’s output under controlled conditions.

- #include <Wire.h>
- #include <DS1307.h>

•
- DS1307 rtc;

•
- void setup()
- {
- //init Serial port
- Serial.begin(9600);
- while(!Serial); //wait for serial port to connect - needed for Leonardo only

•
- //init RTC
- Serial.println("Init RTC...");
- rtc.begin();

•
- //only set the date+time one time
- rtc.set(0, 5, 4, 8, 6, 2024); //08:00:00 24.12.2014 //sec, min, hour, day, month, year

•
- //stop/pause RTC
- // rtc.stop();

•
- //start RTC
- rtc.start();
- }

•
- void loop()
- {
- uint8_t sec, min, hour, day, month;
- uint16_t year;

•
- //get time from RTC

- rtc.get(&sec, &min, &hour, &day, &month, &year);

•
- //serial output
- Serial.print("\nTime: ");
- Serial.print(hour, DEC);
- Serial.print(":");
- Serial.print(min, DEC);
- Serial.print(":");
- Serial.print(sec, DEC);

•
- Serial.print("\nDate: ");
- Serial.print(day, DEC);
- Serial.print(".");
- Serial.print(month, DEC);
- Serial.print(".");
- Serial.print(year, DEC);

•
- //wait a second
- delay(1000);
- }

•

- Result:

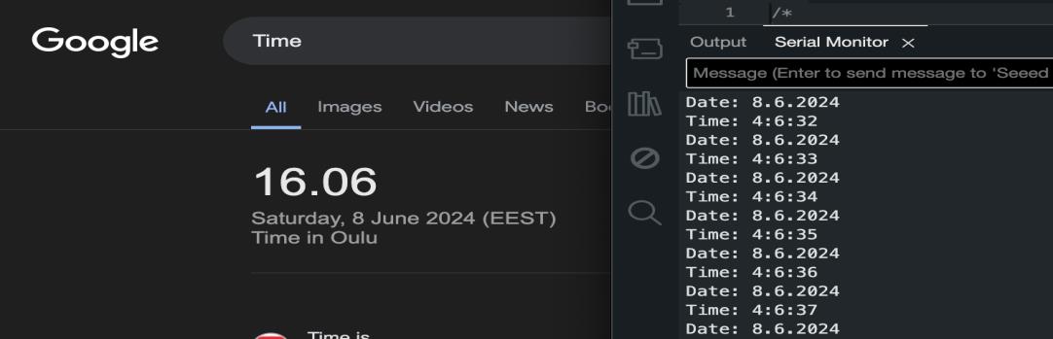
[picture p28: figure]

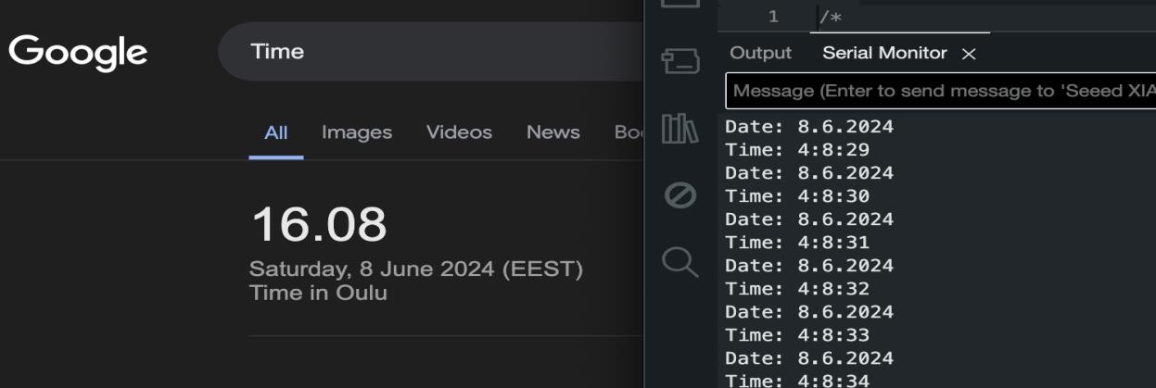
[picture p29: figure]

The DS1307 RTC accurately maintained the time and date, displaying the correct

information on the serial monitor.

4.1.3 Display Tests

- Test Setup: Connect the display to the Seeed Xiao and load test data.
- Procedure: Display “Hello World” on diplay by uploading below code.
- #include <st7789v2.h>
- #include "SPI.h"
- st7789v2 Display;

•
- void setup() {
- // put your setup code here, to run once:
- Display.SetRotate(0);
- Display.Init();
- Display.SetBacklight(100);
- Display.Clear(WHITE);
- }

•
- void loop() {
- // put your main code here, to run repeatedly:
- Display.DrawString_EN(0, 50, " Hello World ", &Font24, WHITE, RED);

•
- }

•

- Result:

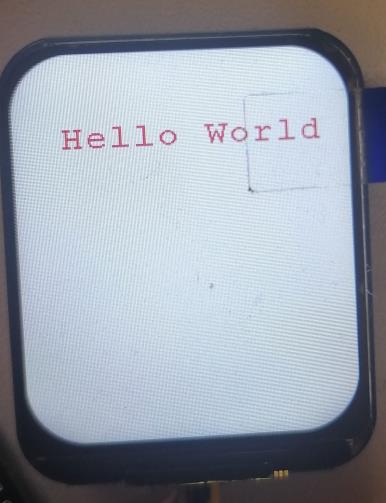
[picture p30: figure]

The display showed the text “Hello World”, confirming that it could display real-

time data accurately.

4.1.4 Power Management Tests

Objective: To verify the power consumption and battery life of the device.

- Test Setup: Fully charge the Li-Po battery and connect it to Seeed Xiao.
- Procedure: Monitor the power consumption during typical usage scenarios and measure the battery life and compare with calculations.

Calculations:

Seeed Xiao Nrf52840 with the connected sensors (LSM6DS3, MAX30105, DS1307,

BME280) when using a 3.7V 300mAh LiPo battery, we need to consider the current draw

of each component and the microcontroller itself.

Step 1: Current Consumption of Each Component

Let's break down the current consumption of each component:

Seeed Xiao Nrf52840

- Active Mode (without BLE): ~6 mA
- Idle Mode: ~1.5 mA
- Deep Sleep: ~0.1 mA

LSM6DS3 (Accelerometer + Gyroscope)

- Active Mode: ~0.67 mA
- Power Down Mode: ~1 µA

MAX30105 (Heart Rate Monitor)

- Typical: ~1.6 mA (continuous monitoring)
- Standby: ~0.7 µA

DS1307 (RTC)

- Typical: ~1.5 mA (when accessing data)
- Standby: ~1.1 µA (when only keeping time)

BME280 (Temperature, Humidity, Pressure)

- Active Mode: ~0.68 mA
- Sleep Mode: ~0.1 µA

ST7789 Display

- Typical: ~7 mA (with backlight on)
- Standby: ~0.2 mA
Step 2: Total Current Consumption Calculation

Assuming all components are active all the time (no sleep Mode):

- Seeed Xiao Nrf52840 (Active): 6 mA
- LSM6DS3 (Active Mode): 0.67 mA
- MAX30105 (Typical): 1.6 mA
- DS1307 (Typical): 1.5 mA
- BME280 (Active Mode): 0.68 mA
- ST7789 Display (Active Mode with backlight): 7 mA

Total current consumption:

6 mA + 0.67 mA + 1.6 mA + 1.5 mA + 0.68 mA +7 mA = 17.45 mA

Step 3: Battery Life Calculation

Using a 3.7V, 300mAh LiPo battery:

Battery capacity in mAh: 300 mAh

Battery capacity in Ah: 300 mAh = 0.3 Ah

Battery life (in hours):

Battery Life = Battery Capacity (Ah) / Total Current Consumption (A)

Battery Life = 0.3 Ah / 0.01745 A ≈ 17.2 hours

The Seeed Xiao Nrf52840 with the LSM6DS3, MAX30105, DS1307, and BME280

connected and all components active, excluding BLE, would consume approximately

17.45 mA. Using a 3.7V 300mAh LiPo battery, the system would run for approximately

17.2 hours.

4.2 System Tests

System tests were conducted to validate the overall functionality, performance, and

reliability of the Seeed Xiao Nrf52840-Based Health and Fitness Monitoring System in real-world conditions. These tests ensured that the integrated system met all specified

requirements and performed as expected during typical usage scenarios.

1) When Smart watch is Powered it shows Date and Time as below on Display.
2) When Button is pressed, screen changes and shows Heart Rate as below on Display.

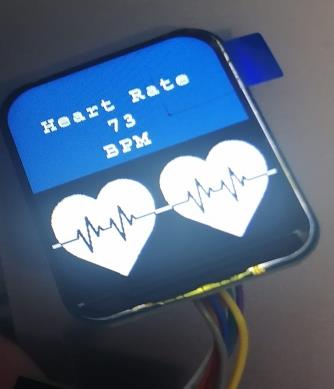
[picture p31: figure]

3) When Button is pressed, screen changes and shows Tempertature and Humidity as

below on Display.

4) When Button is pressed, screen changes and shows Altitude and Pressure as below

on Display.

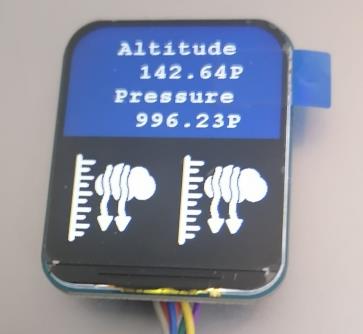
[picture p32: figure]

5) When Button is pressed, screen changes and shows Steps Count as below on Display

and so on.

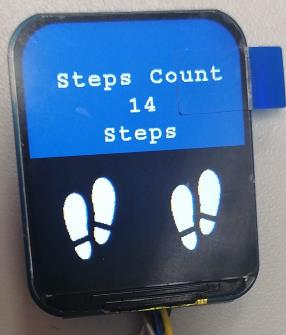
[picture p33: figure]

### 5 Challenges and Future Improvements

5.1 Challenges Encountered:

1. Component Availability: There were delays in procuring certain sensors, which

impacted the initial timeline.

2. Firmware Bugs: Initial firmware development faced issues with sensor data

acquisition, requiring extensive debugging and testing.

3. Power Management: Achieving optimal power consumption while maintaining

functionality was challenging, especially with the display's power demands.

4. Integration Issues: Combining multiple sensors and ensuring seamless data flow

and display required careful handling of I2C and SPI communication protocols.

5. PCB Design Flaw: Initially, the ground connection was not correctly implemented in the

PCB design. After the PCBs were ordered, it was discovered that the ground was not

connected, necessitating the use of a jumper wire to establish the connection.

6. I2C Communication Issues: The I2C connection did not function correctly because the

SCL and SDA lines for an optional OLED were left floating when the OLED was not

connected. This issue was resolved by adding a 10k pull-up resistor to the 3.3V line.

7. MAX30102 Sensor Stabilization: The MAX30102 sensor took a significant

amount of time to stabilize, causing initial inconsistencies in heart rate and SpO2

readings.

5.2 Future Improvements:

1. Enhanced Power Management: Implement more sophisticated power-saving

modes and dynamic power scaling based on sensor activity.

2. Expanded Features: Incorporate additional health metrics and environmental

sensors to provide more comprehensive data.

3. User Interface Improvements: Develop a more intuitive and customizable user

interface for better user experience.

4. Wireless Connectivity: Add features for wireless data synchronization and remote

monitoring through Bluetooth or Wi-Fi.

5. Improved Enclosure Design: Use more durable materials for the device enclosure

to enhance robustness and water resistance.

### 6 Feedback and Experience

Working on this project provided invaluable experience in embedded system design and

integration. The challenges faced helped improve problem-solving skills and deepen the

understanding of hardware-software interaction. The course offered a comprehensive

insight into practical applications of theoretical knowledge, making the overall experience

highly beneficial.

### 7 References

1) https://www.analog.com/media/en/technical-documentation/data-sheets/max30102.pdf
2) https://www.instructables.com/How-to-Build-a-DIY-WiFi-Smart-Oximeter-Using-

MAX30/ (https://www.instructables.com/How-to-Build-a-DIY-WiFi-Smart-Oximeter-Using-MAX30/)

3) https://www.mouser.com/datasheet/2/783/BST-BME280-DS002-1509607.pdf
4) https://lastminuteengineers.com/bme280-arduino-tutorial/
5) https://www.analog.com/media/en/technical-documentation/data-sheets/ds1307.pdf
6) https://content.arduino.cc/assets/st_imu_lsm6ds3_datasheet.pdf
7) https://www.robotics.org.za/GY-LSM6DS3

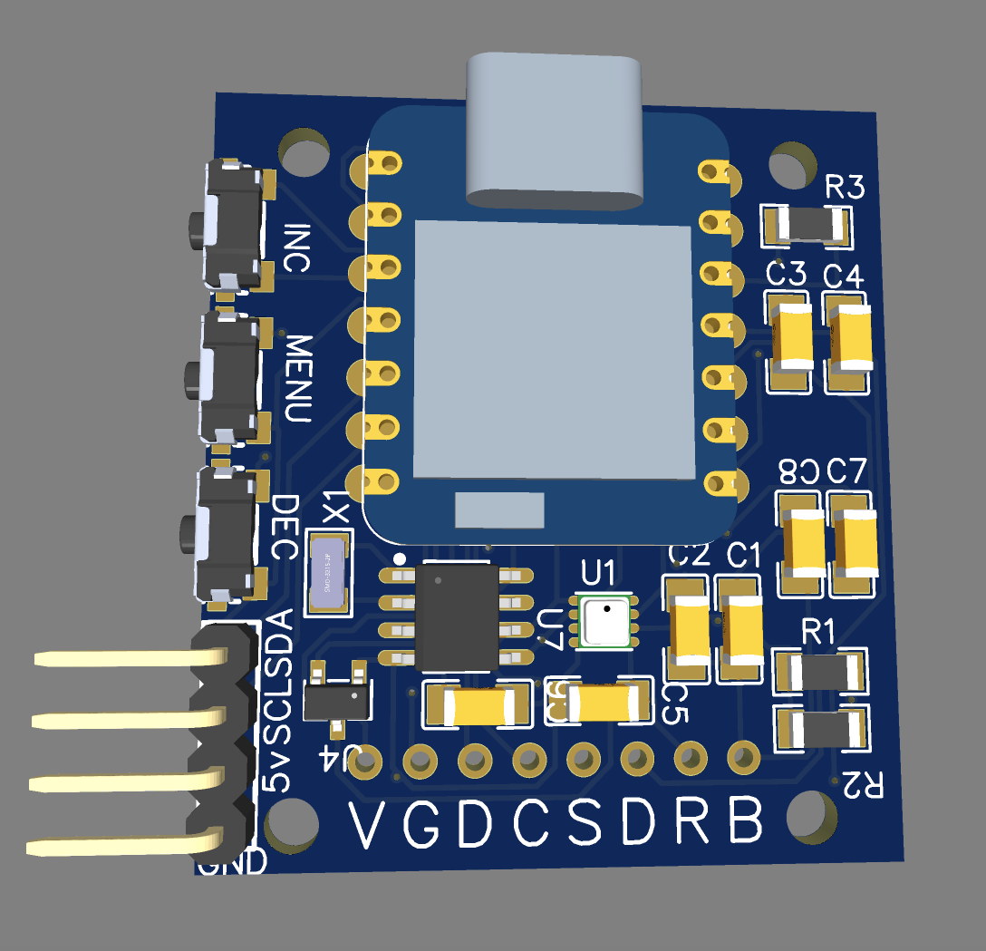
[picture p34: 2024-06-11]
PCB/Smart_Watch_PCB_3d.png

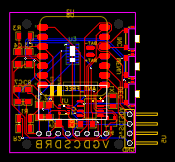
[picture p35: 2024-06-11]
PCB/PCB_PCB_smart_watch_2024-06-11 (1).png

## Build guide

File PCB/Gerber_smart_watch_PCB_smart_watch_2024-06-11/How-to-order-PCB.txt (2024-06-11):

How to Order PCB

Please refer to:
https://docs.easyeda.com/en/PCB/Order-PCB

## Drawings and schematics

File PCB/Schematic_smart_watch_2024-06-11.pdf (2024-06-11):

## 1.69inch LCD

240x280

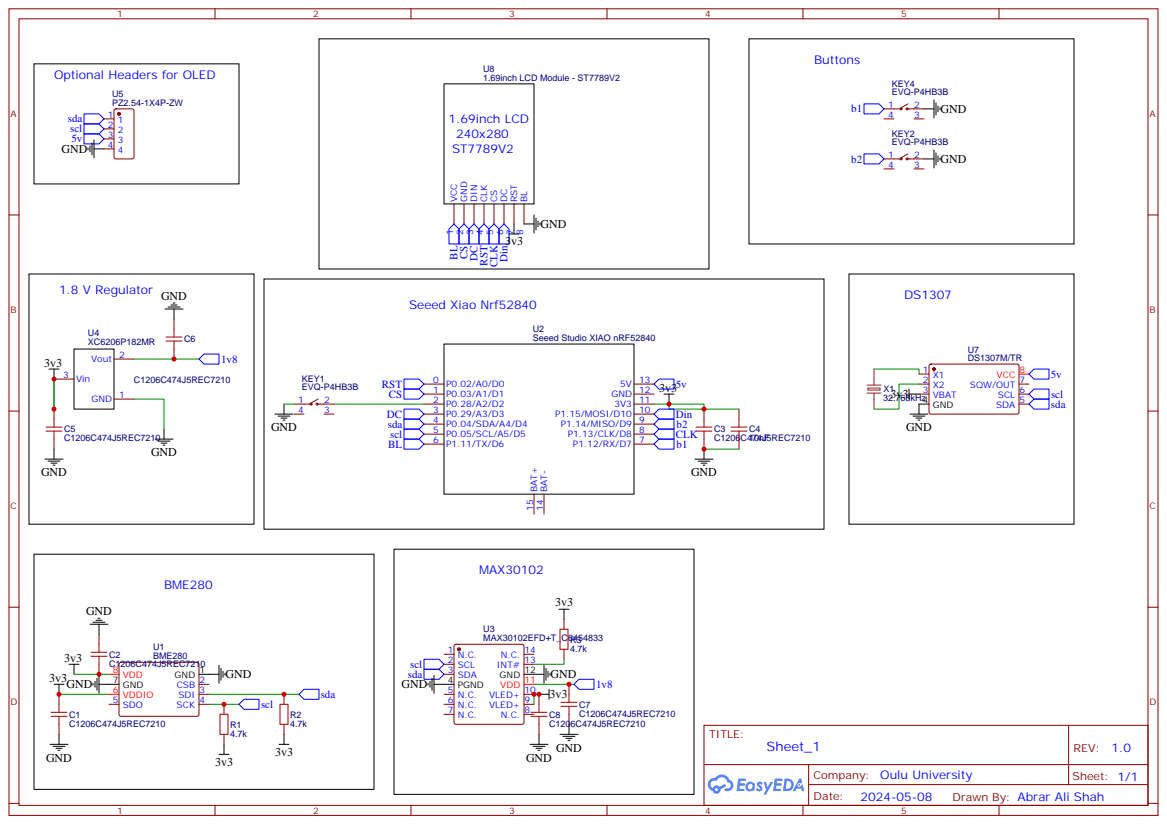
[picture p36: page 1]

Optional Headers for OLED

Drawn By: Abrar Ali Shah
